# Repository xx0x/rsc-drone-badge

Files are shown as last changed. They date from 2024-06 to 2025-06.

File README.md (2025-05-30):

# RSC Drone Badge

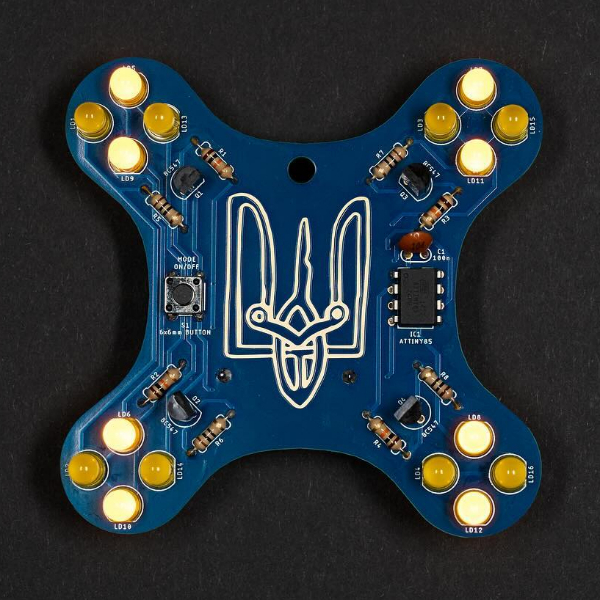
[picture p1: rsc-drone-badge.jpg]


A badge (pendant) in the shape of FPV drone which I designed for my friends at [Resistance Support Club](http://resistance.support). The collective organizes soldering workshops, the collected money goes to Ukrainian defenders.

## BOM (Bill of Material)
<table>
    <tr>
        <th>Part</th>
        <th>Value</th>
        <th>Package</th>
        <th>Part number</th>
        <th>Qty</th>
    </tr>
    <tr>
        <td>IC1</td>
        <td>ATTINY</td>
        <td>DIP8</td>
        <td>ATTINY25V-10PU</td>
        <td>1</td>
    </tr>
    <tr>
        <td>LD1, LD2, LD3, LD4,<br>LD5, LD6, LD7, LD8,<br>LD9, LD10, LD11, LD12,<br>LD13, LD14, LD15, LD16</td>
        <td>Yellow LED</td>
        <td>5mm THT</td>
        <td>N0Y64L35,<br>L-53SYD</td>
        <td>16</td>
    </tr>
    <tr>
        <td>Q1, Q2, Q3, Q4</td>
        <td>BC547</td>
        <td>TO92</td>
        <td>BC547A/B/C</td>
        <td>4</td>
    </tr>
    <tr>
        <td>R1, R2, R3, R4</td>
        <td>10K</td>
        <td>0207</td>
        <td>CF1/4W-10K</td>
        <td>4</td>
    </tr>
    <tr>
        <td>R5, R6, R7, R8</td>
        <td>10R</td>
        <td>0207</td>
        <td>CF1/4W-10R</td>
        <td>4</td>
    </tr>
    <tr>
        <td>C1</td>
        <td>100n</td>
        <td>2.54 ceramic</td>
        <td>CC-100N</td>
        <td>1</td>
    </tr>
    <tr>
        <td>S1</td>
        <td>Tactile button</td>
        <td>6x6mm</td>
        <td>TACT-64K-F,<br>B3F-1020</td>
        <td>1</td>
    </tr>
    <tr>
        <td>BAT</td>
        <td>Battery holder</td>
        <td>CR2032</td>
        <td>DS1092-04-B6P</td>
        <td>1</td>
    </tr>
</table>

Then you just need a regular CR2032 battery and a 2 mm polypropylen, nylon or other string from your local store.

## Description

Custom designed PCB in Eagle, you can find both design files and gerber archive in the `pcb` subfolder. You can easily download the ZIP file with gerber and order the PCBs at your favorite PCB manufacturer. Recommended options are: Blue soldermask, ENIG surface.

The board contains ATtiny 25 MCU, you can find a precompiled HEX and shell upload script in `build` folder. Or you can compile it by yourself, eg. to run on another MCU like ATtiny 85. The source files are in the `code` folder, you'll need Arduino IDE with ATTinyCore for compiling them.

In `drawing` subfolder you can find board drawings in Adobe Illustrator format and a PDF with BOM and build instructions.

Слава Україні! 🇺🇦

## Mini Variant

The directories also contain a simplified variant, smaller with 4 LEDs.

## License

MIT, feel free to share!

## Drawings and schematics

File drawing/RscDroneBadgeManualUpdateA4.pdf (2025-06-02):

# RSC Přívěsek RSC Přívěsek

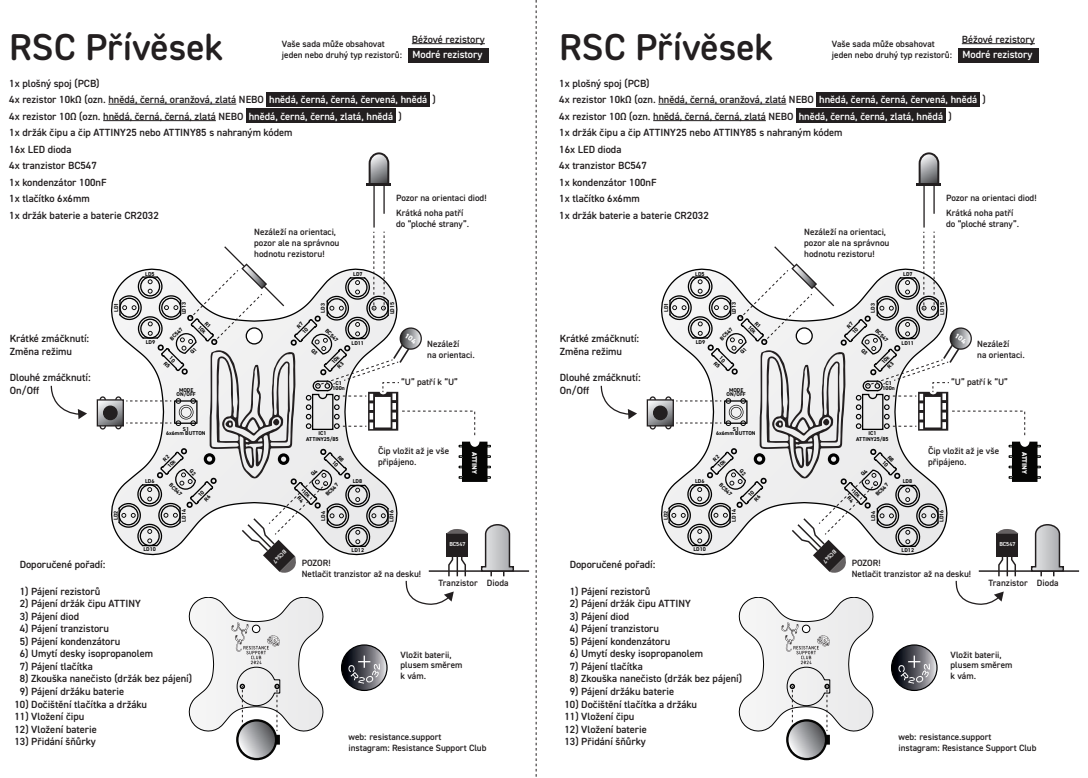
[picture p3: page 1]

Vaše sada může obsahovat
jeden nebo druhý typ rezistorů:

1x plošný spoj (PCB)
4x rezistor 10kΩ (ozn. hnědá, černá, oranžová, zlatá NEBO hnědá, černá, černá, červená, hnědá )
4x rezistor 10Ω (ozn. hnědá, černá, černá, zlatá NEBO hnědá, černá, černá, zlatá, hnědá )
1x držák čipu a čip ATTINY25 nebo ATTINY85 s nahraným kódem
16x LED dioda
4x tranzistor BC547
1x kondenzátor 100nF
1x tlačítko 6x6mm
1x držák baterie a baterie CR2032

Pozor na orientaci diod!
Krátká noha patří
do “ploché strany”.

Nezáleží na orientaci,
pozor ale na správnou
hodnotu rezistoru!

Čip vložit až je vše
připájeno.

POZOR!
Netlačit tranzistor až na desku!

1) Pájení rezistorů
2) Pájení držák čipu ATTINY
3) Pájení diod
4) Pájení tranzistoru
5) Pájení kondenzátoru
6) Umytí desky isopropanolem
7) Pájení tlačítka
8) Zkouška nanečisto (držák bez pájení)
9) Pájení držáku baterie
10) Dočištění tlačítka a držáku
11) Vložení čipu
12) Vložení baterie
13) Přidání šňůrky

web: resistance.support
instagram: Resistance Support Club

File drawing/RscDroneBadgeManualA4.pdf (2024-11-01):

# RSC Přívěsek RSC Přívěsek

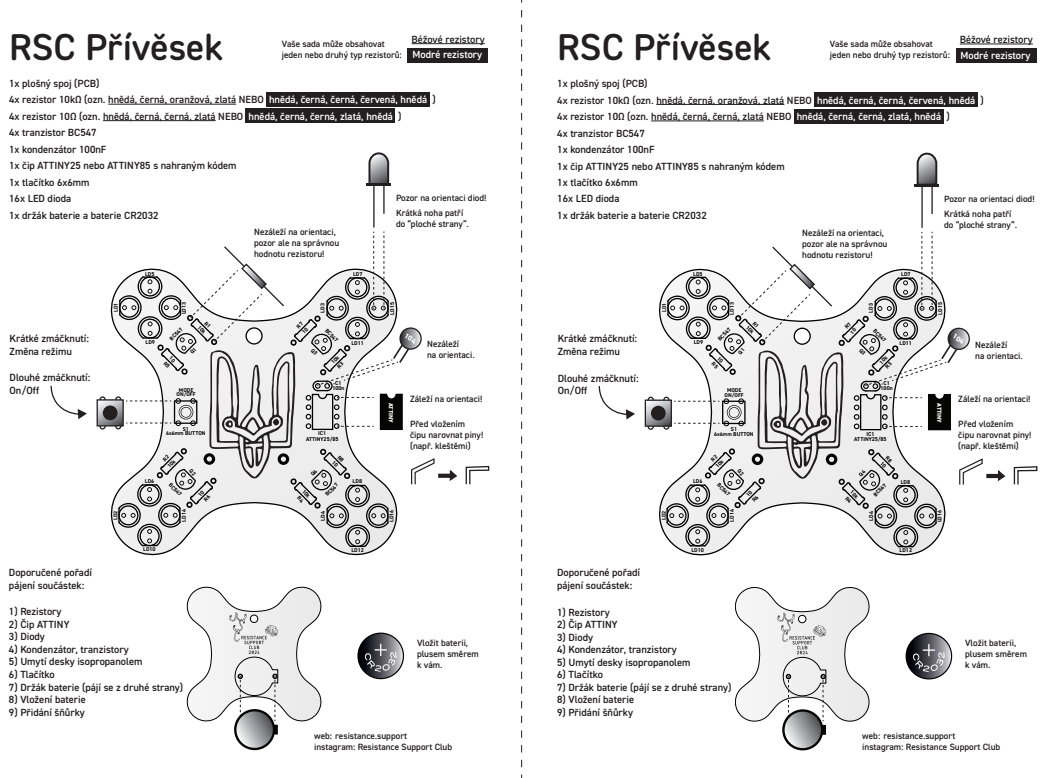
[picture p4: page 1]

Vaše sada může obsahovat
jeden nebo druhý typ rezistorů:

1x plošný spoj (PCB)
4x rezistor 10kΩ (ozn. hnědá, černá, oranžová, zlatá NEBO hnědá, černá, černá, červená, hnědá )
4x rezistor 10Ω (ozn. hnědá, černá, černá, zlatá NEBO hnědá, černá, černá, zlatá, hnědá )
4x tranzistor BC547
1x kondenzátor 100nF
1x čip ATTINY25 nebo ATTINY85 s nahraným kódem
1x tlačítko 6x6mm
16x LED dioda
1x držák baterie a baterie CR2032

Pozor na orientaci diod!
Krátká noha patří
do “ploché strany”.

Nezáleží na orientaci,
pozor ale na správnou
hodnotu rezistoru!

1) Rezistory
2) Čip ATTINY
3) Diody
4) Kondenzátor, tranzistory
5) Umytí desky isopropanolem
6) Tlačítko
7) Držák baterie (pájí se z druhé strany)
8) Vložení baterie
9) Přidání šňůrky

web: resistance.support
instagram: Resistance Support Club

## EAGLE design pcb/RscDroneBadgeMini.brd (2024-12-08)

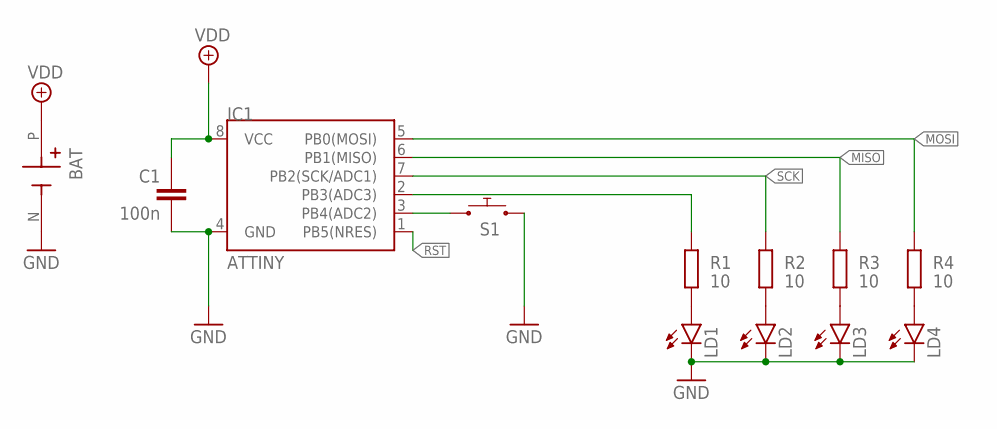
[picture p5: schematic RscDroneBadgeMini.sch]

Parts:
BAT: CR2032; CR2032_PLASTIC
C1: 100n; C_2.54
IC1: ATTINY; DIL08
LD1, LD2, LD3, LD4: LED_THT-5MM_NICE; LED_5MM_NICE
R1, R2, R3, R4: 10; RCL_0207
S1: 6x6mm BUTTON; TACTILE-PTH

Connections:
GND: BAT.N (NEG), C1.2, IC1.4 (GND), LD1.K (C), LD2.K (C), LD3.K (C), LD4.K (C), S1.3 (2), S1.4 (2)
MISO: IC1.6 (PB1(MISO)), R3.2
MOSI: IC1.5 (PB0(MOSI)), R4.2
unnamed: IC1.3 (PB4(ADC2)), S1.1, S1.2 (1)
unnamed: LD1.A, R1.1
unnamed: LD2.A, R2.1
unnamed: LD3.A, R3.1
unnamed: LD4.A, R4.1
unnamed: IC1.2 (PB3(ADC3)), R1.2
RST: IC1.1 (PB5(NRES))
SCK: IC1.7 (PB2(SCK/ADC1)), R2.2
VDD: BAT.P (POS), C1.1, IC1.8 (VCC)

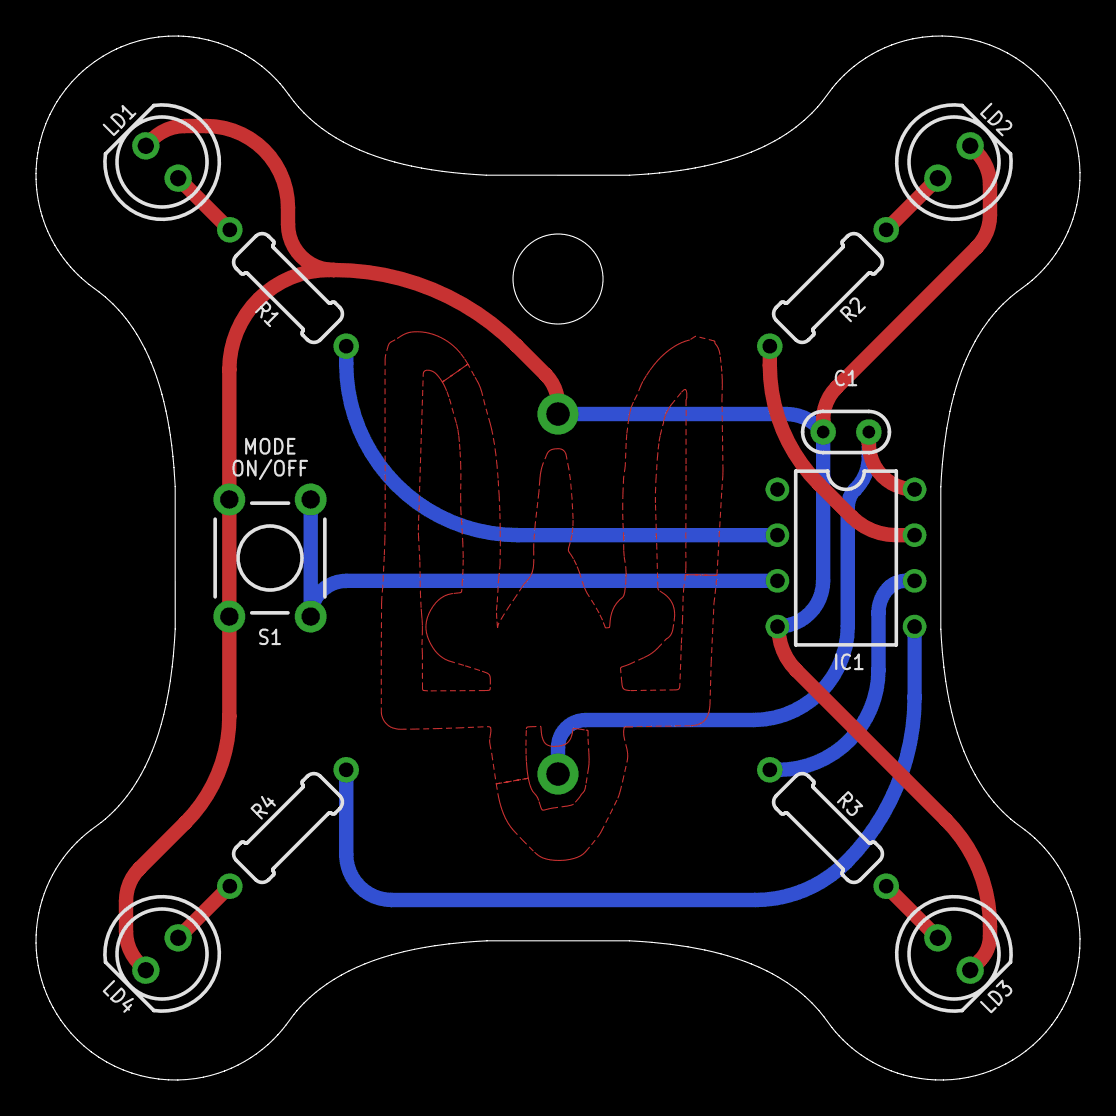
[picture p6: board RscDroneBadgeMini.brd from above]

Board: 2 copper layers, 58.0 x 58.0 mm, 12 parts (1 on the bottom side), 11 nets.

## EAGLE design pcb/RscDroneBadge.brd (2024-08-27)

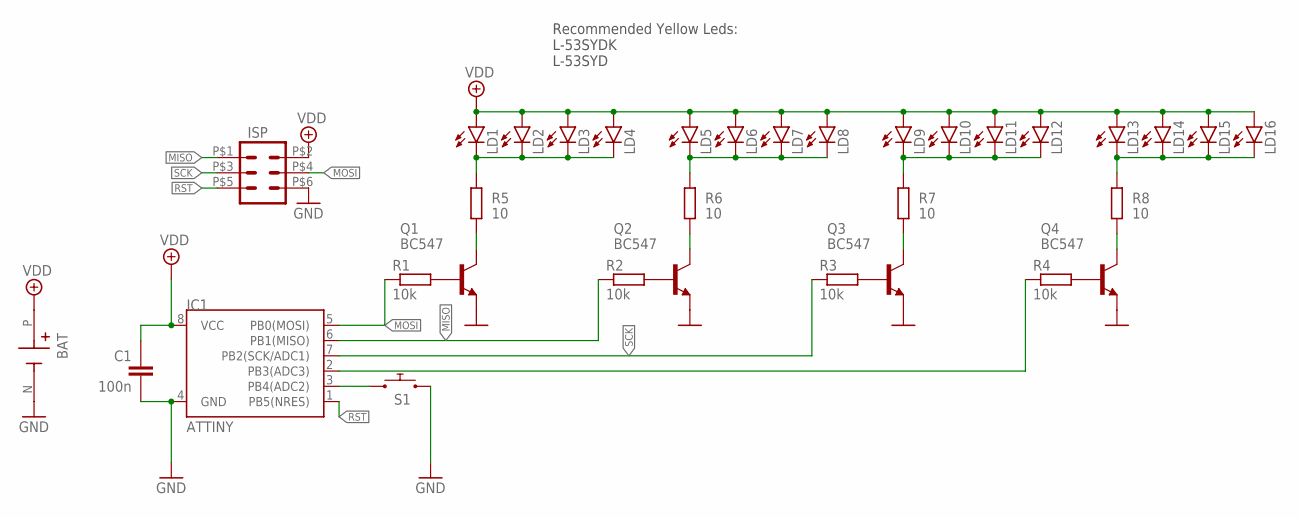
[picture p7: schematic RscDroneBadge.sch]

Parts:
BAT: CR2032 HOLDER; CR2032_PLASTIC
C1: 100n; C_2.54
IC1: ATTINY; DIL08
ISP: 2X3POGONO_VIA; 2X3_POGO_NO_VIA
LD1, LD2, LD3, LD4, LD5, LD6, LD7, LD8, LD9, LD10, LD11, LD12, LD13, LD14, LD15, LD16: LED_THT-5MM_NICE; LED_5MM_NICE
Q1, Q2, Q3, Q4: BC547; TO92_ROUND
R1, R2, R3, R4: 10k; RCL_0207
R5, R6, R7, R8: 10; RCL_0207
S1: 6x6mm BUTTON; TACTILE-PTH

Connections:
GND: BAT.N (NEG), C1.2, IC1.4 (GND), ISP.P$6 (6), Q1.1 (E), Q2.1 (E), Q3.1 (E), Q4.1 (E), S1.3 (2), S1.4 (2)
MISO: IC1.6 (PB1(MISO)), ISP.P$1 (1), R2.1
MOSI: IC1.5 (PB0(MOSI)), ISP.P$4 (4), R1.1
unnamed: IC1.3 (PB4(ADC2)), S1.1, S1.2 (1)
unnamed: Q1.2 (B), R1.2
unnamed: Q2.2 (B), R2.2
unnamed: Q3.2 (B), R3.2
unnamed: Q4.2 (B), R4.2
unnamed: IC1.2 (PB3(ADC3)), R4.1
unnamed: Q1.3 (C), R5.1
unnamed: Q2.3 (C), R6.1
unnamed: Q3.3 (C), R7.1
unnamed: Q4.3 (C), R8.1
unnamed: LD9.K (C), LD10.K (C), LD11.K (C), LD12.K (C), R7.2
unnamed: LD13.K (C), LD14.K (C), LD15.K (C), LD16.K (C), R8.2
unnamed: LD5.K (C), LD6.K (C), LD7.K (C), LD8.K (C), R6.2
unnamed: LD1.K (C), LD2.K (C), LD3.K (C), LD4.K (C), R5.2
RST: IC1.1 (PB5(NRES)), ISP.P$5 (5)
SCK: IC1.7 (PB2(SCK/ADC1)), ISP.P$3 (3), R3.1
VDD: BAT.P (POS), C1.1, IC1.8 (VCC), ISP.P$2 (2), LD1.A, LD2.A, LD3.A, LD4.A, LD5.A, LD6.A, LD7.A, LD8.A, LD9.A, LD10.A, LD11.A, LD12.A, LD13.A, LD14.A, LD15.A, LD16.A

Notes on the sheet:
Recommended Yellow Leds: L-53SYDK L-53SYD

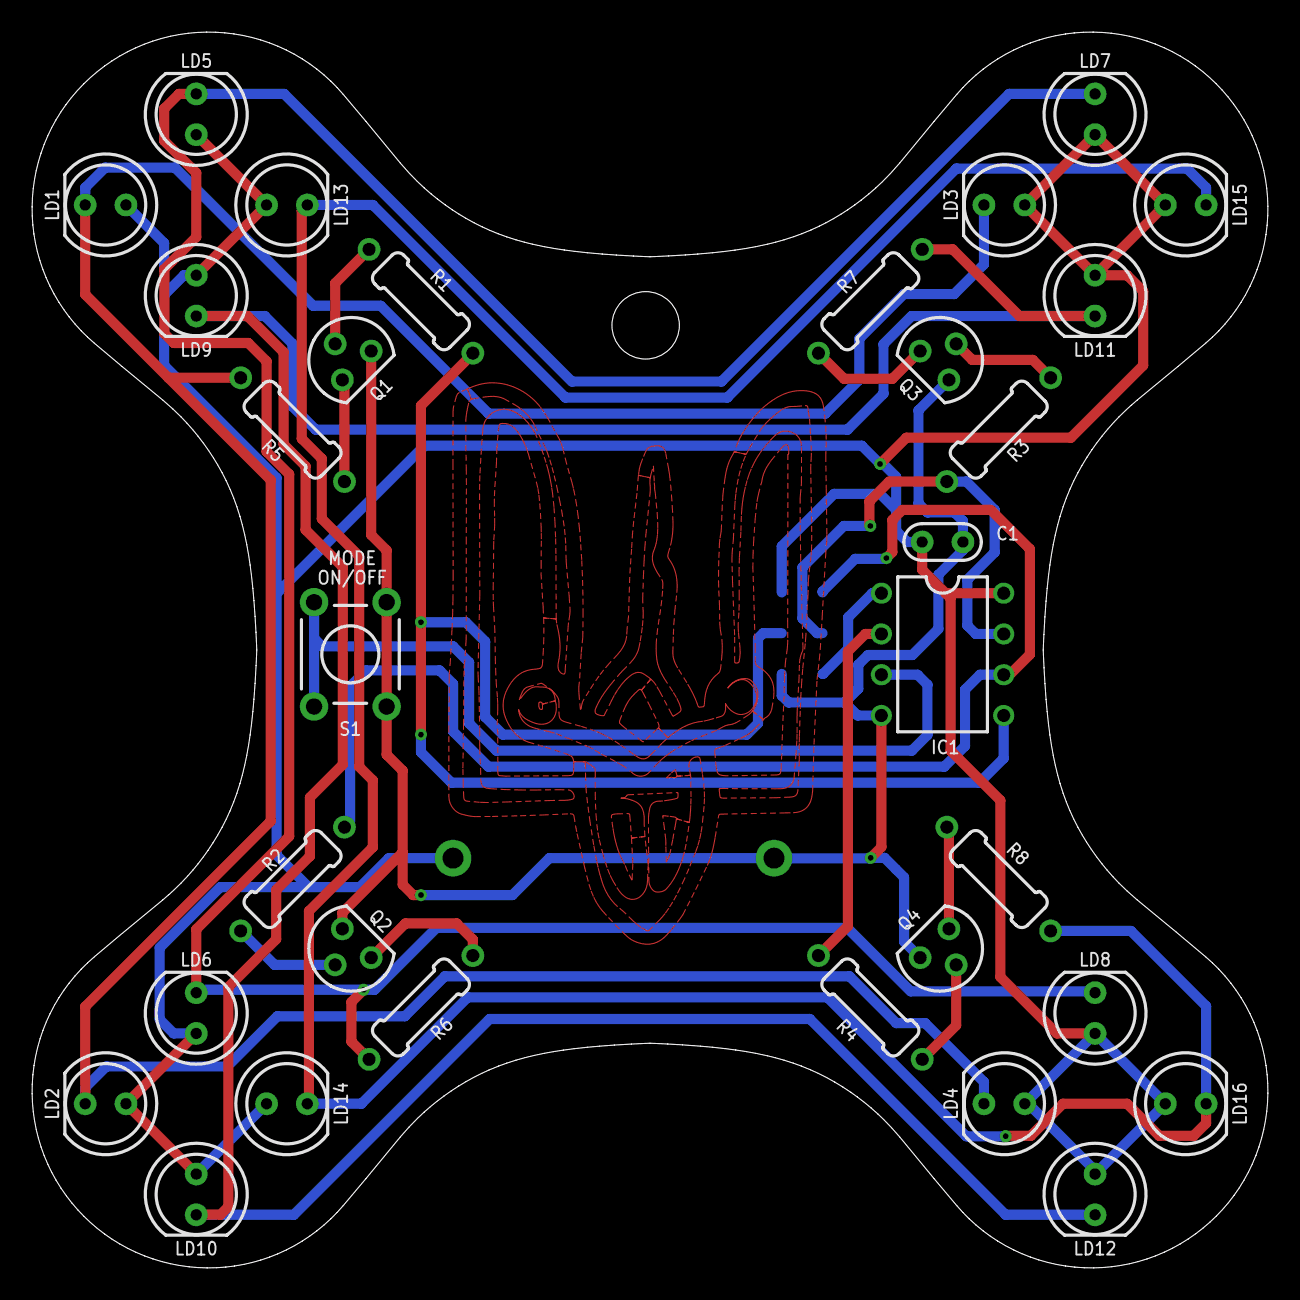
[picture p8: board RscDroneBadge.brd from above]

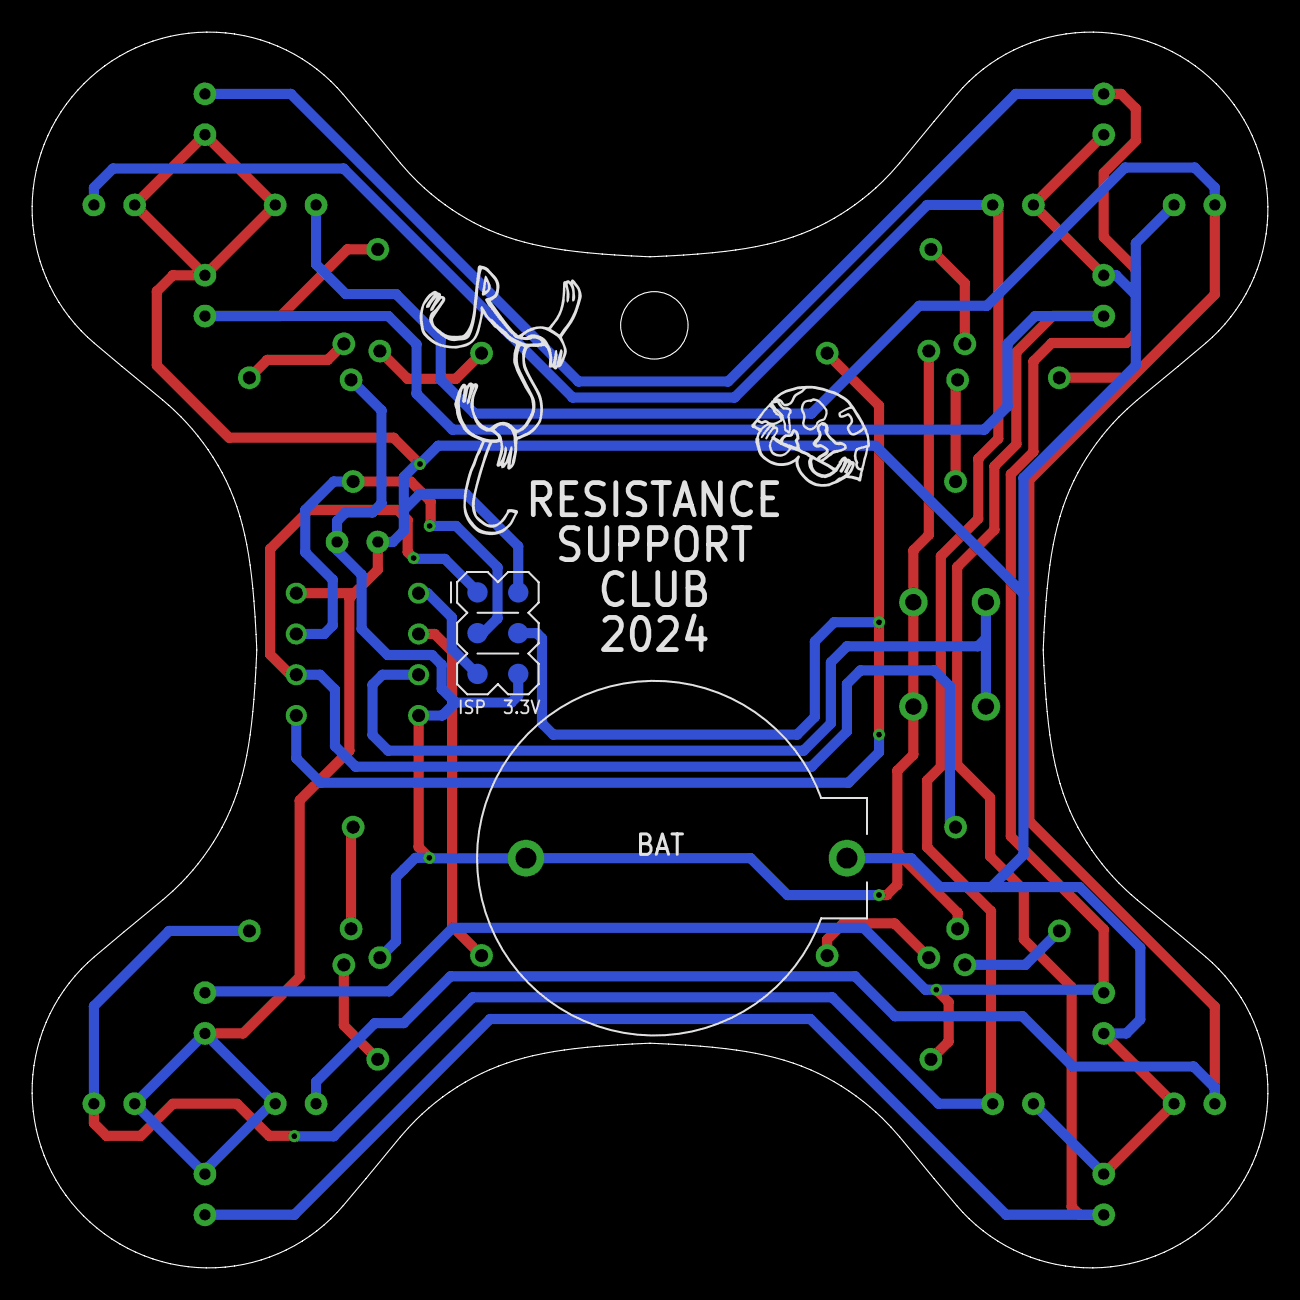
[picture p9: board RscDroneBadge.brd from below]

Board: 2 copper layers, 77.0 x 77.0 mm, 33 parts (2 on the bottom side), 20 nets.

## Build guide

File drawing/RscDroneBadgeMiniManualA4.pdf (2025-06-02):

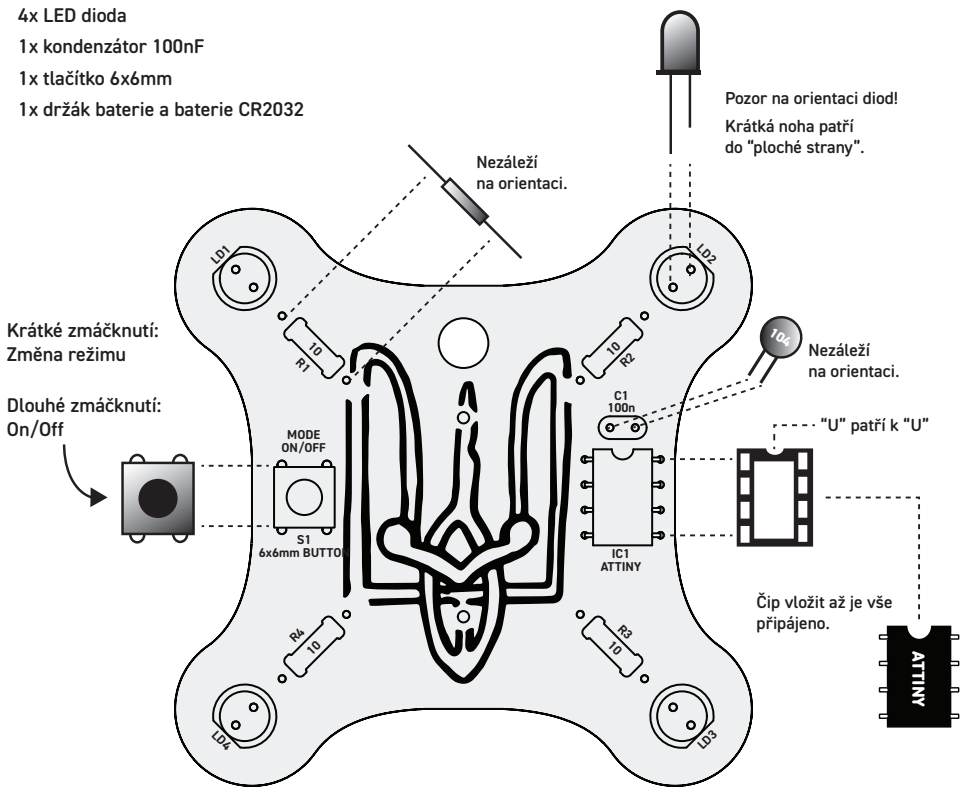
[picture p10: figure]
S1 6x6mm BUTTON; MODE ON/OFF; IC1 ATTINY; 4x LED dioda 1x kondenzátor 100nF 1x tlačítko 6x6mm; Krátká noha patří do “ploché strany”.; Nezáleží na orientaci.; “U” patří k “U”; ATTINY; Krátké zmáčknutí: Změna režimu; Dlouhé zmáčknutí: On/Off; Čip vložit až je vše připájeno.

RESISTANCE SUPPORT
CLUB 2024

# RSC Přívěsek

1x plošný spoj (PCB)
4x rezistor 10Ω (ozn. hnědá, černá, černá, zlatá NEBO hnědá, černá, černá, zlatá, hnědá ) 1x držák čipu a samotný čip ATTINY25 nebo ATTINY85 s nahraným kódem

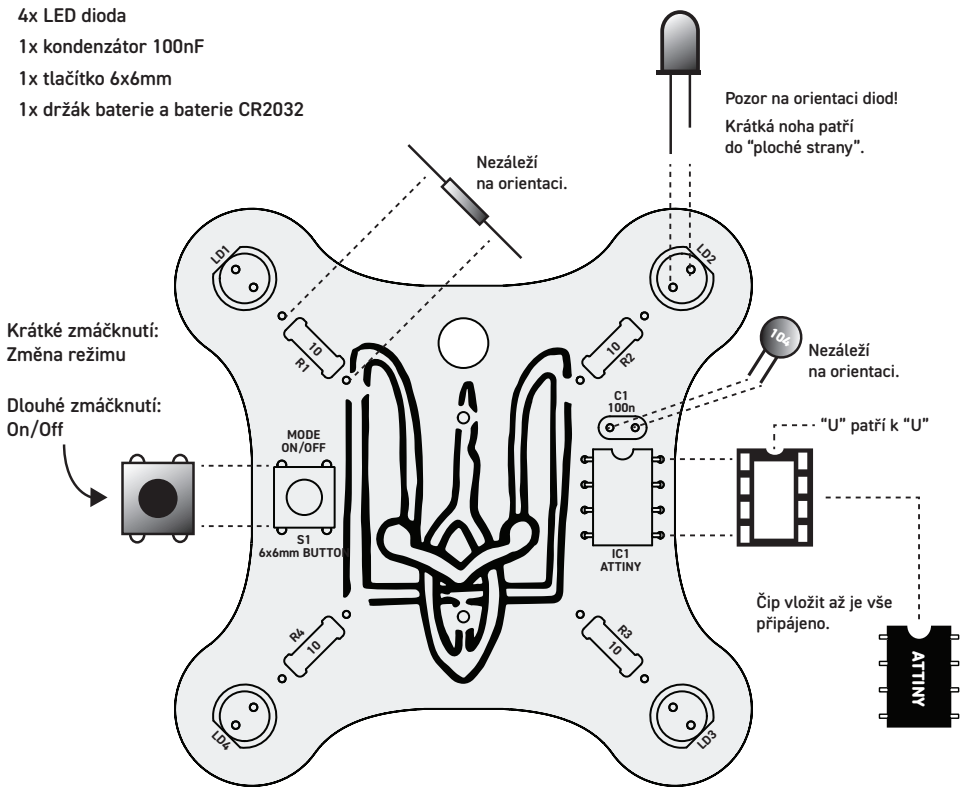
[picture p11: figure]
S1 6x6mm BUTTON; MODE ON/OFF; IC1 ATTINY; 4x LED dioda 1x kondenzátor 100nF 1x tlačítko 6x6mm; Krátká noha patří do “ploché strany”.; Nezáleží na orientaci.; “U” patří k “U”; ATTINY; Krátké zmáčknutí: Změna režimu; Dlouhé zmáčknutí: On/Off; Čip vložit až je vše připájeno.

1x držák baterie a baterie CR2032 | Pozor na orientaci diod!

Vložit baterii,
plusem směrem
k vám.

Béžové rezistory
Modré rezistory

Vaše sada může obsahovat
jeden nebo druhý typ rezistorů:

Doporučené pořadí:

1) Pájení rezistorů
2) Pájení držák čipu ATTINY
3) Pájení diod
4) Pájení kondenzátoru
5) Umytí desky isopropanolem
6) Pájení tlačítka
7) Zkouška nanečisto (držák bez pájení)
8) Pájení držáku baterie
9) Dočištění tlačítka a držáku
10) Vložení čipu
11) Vložení baterie
12) Přidání šňůrky
web: resistance.support
instagram: Resistance Support Club

## MINI

RESISTANCE SUPPORT
CLUB 2024

# RSC Přívěsek

1x plošný spoj (PCB)
4x rezistor 10Ω (ozn. hnědá, černá, černá, zlatá NEBO hnědá, černá, černá, zlatá, hnědá ) 1x držák čipu a samotný čip ATTINY25 nebo ATTINY85 s nahraným kódem
1x držák baterie a baterie CR2032 | Pozor na orientaci diod!

Vložit baterii,
plusem směrem
k vám.

Béžové rezistory
Modré rezistory

Vaše sada může obsahovat
jeden nebo druhý typ rezistorů:

Doporučené pořadí:

1) Pájení rezistorů
2) Pájení držák čipu ATTINY
3) Pájení diod
4) Pájení kondenzátoru
5) Umytí desky isopropanolem
6) Pájení tlačítka
7) Zkouška nanečisto (držák bez pájení)
8) Pájení držáku baterie
9) Dočištění tlačítka a držáku
10) Vložení čipu
11) Vložení baterie
12) Přidání šňůrky
web: resistance.support
instagram: Resistance Support Club

## MINI

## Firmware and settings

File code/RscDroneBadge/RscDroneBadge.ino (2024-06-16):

/**
 * Code for RSC DRONE BADGE
 * MCU: ATTINY25 @ 8 MHz
 * Using: Arduino + ATTinyCore
 * Author: Vaclav M (github.com/xx0x)
 * Licence: MIT
 *
 * Ugly code, sorry, I wrote in a hurry and didn't have time to clean it :(
 * But it works :)
 */

#include <avr/interrupt.h>
#include <avr/sleep.h>


#define LEDS 4
uint8_t ledPins[LEDS] = { 0, 1, 3, 2 };
uint8_t ledPinsFast[LEDS] = { PB0, PB1, PB3, PB2 };

#define SET_STATE_HIGH(pin_name) (PORTB |= (1 << pin_name))
#define SET_STATE_LOW(pin_name) (PORTB &= ~(1 << pin_name))
#define SET_STATE(pin_name, state) ((state) ? SET_STATE_HIGH(pin_name) : SET_STATE_LOW(pin_name))

#define ON HIGH
#define OFF LOW

#define PIN_BUTTON 4
#define BUTTON_PRESSED LOW

#define INTERVAL_NORMAL 250
#define INTERVAL_FAST 100

/*
 * Animations
 */
byte animationType = 0;                // current animation
unsigned int animationInterval = 250;  // interval between animation frames
byte animationFrame = 0;               // current animation frame
unsigned long lastTime = 0;            // last time in milliseconds the frame changed
byte animationEnabled = true;          // whether animations enabled

/*
 * PWM - brightness settings
 */
#define PWM_MODES 4
byte currentPwmMode = 0;
byte pwmModes[PWM_MODES] = { 0, 10, 50, 250 };
byte pwmIndex = 0;


/*
 * Buttons
 */
bool buttonPressed = false;        // whether mode button pressed last time
unsigned long lastTimeButton = 0;  // last time - used for turning off
bool modeChangeDisabled = false;   // if changing pwm or turning on, mode change disabled when button released

/*
 * Turn off interval
 */
#define TURN_OFF_INTERVAL 1000


bool leds[LEDS] = { 0, 0, 0, 0 };

#define ANIMATIONS 9  // animations count
#define ANIMATION_RANDOM 8
uint8_t randomAnimation = 1;
uint16_t randomFramesCounter = 0;

void animate() {

  animationInterval = INTERVAL_NORMAL;
  uint8_t animationTypeNow = animationType;
  if(animationTypeNow == ANIMATION_RANDOM){
    randomFramesCounter++;
    if(randomFramesCounter > 8){
        byte x = 0;
        do {
            x = (rand() % 7) + 1;
        } while(x == randomAnimation);
        randomAnimation = x;
        randomFramesCounter = 0;
        animationFrame = 0;
    }
    animationTypeNow = randomAnimation;
  }

  switch (animationTypeNow) {
    case 0:
      animationOn();
      break;
    case 1:
      animationAllBlink();
      break;
    case 2:
      animationRotateProper();
      break;
    case 3:
      animationInterval = INTERVAL_FAST;
      animationRotateProper();
      break;
    case 4:
      animationRotate();
      break;
    case 5:
      animationInterval = INTERVAL_FAST;
      animationRotate();
      break;
    case 6:
      animationRotateBackwards();
      break;
    case 7:
      animationInterval = INTERVAL_FAST;
      animationRotateBackwards();
      break;
  }
}

void animationOff() {
  for (uint8_t i = 0; i < LEDS; i++) {
    leds[i] = 0;
  }
}

void animationOn() {
  for (uint8_t i = 0; i < LEDS; i++) {
    leds[i] = 1;
  }
}

void animationAllBlink() {
  switch (animationFrame) {
    case 0:
      animationOn();
      animationFrame++;
      break;
    case 1:
      animationOff();
      animationFrame = 0;
      break;
  }
}

void animationRotate() {
  animationFrame = (animationFrame + 1) % LEDS;
  animationOff();
  leds[animationFrame] = 1;
}

void animationRotateBackwards() {
  animationFrame = (animationFrame + 1) % LEDS;
  animationOff();
  leds[LEDS - animationFrame - 1] = 1;
}

void animationRotateProper() {
  animationFrame = (animationFrame + 1) % 2;
  animationOff();
  leds[animationFrame] = 1;
  leds[animationFrame + 2] = 1;
}

void animationRandom() {
  for (uint8_t i = 0; i < LEDS; i++) {
    leds[i] = (random(10) > 7);
  }
}


/* 
 *  The setup function runs once when the battery is inserted (not when "turned off" via button)
 */
void setup() {
  for (uint8_t i = 0; i < LEDS; i++) {
    pinMode(ledPins[i], OUTPUT);
  }
  pinMode(PIN_BUTTON, INPUT_PULLUP);
}


/* 
 * The loop function runs over and over again forever
 */
void loop() {

  // debounce to prevent double taps
  if (millis() - lastTimeButton > 200) {
    /*
     * BUTTON MODE switches animations, but after is released (because of PWM and turning off)
     */
    if (digitalRead(PIN_BUTTON) == BUTTON_PRESSED) {
      if (!buttonPressed) {
        buttonPressed = true;
        lastTimeButton = millis();
      }
      checkWhetherToSleep();  // checking whether to sleep
    } else {

      lastTimeButton = 0;

      // if mode released, change mode
      if (buttonPressed) {
        if (!modeChangeDisabled) {  // changing modes is disabled after waking up
          lastTime = 0;
          animationType = (animationType + 1) % ANIMATIONS;
          if (animationType == 0) {
            currentPwmMode = (currentPwmMode + 1) % PWM_MODES;
          }
          animationFrame = 0;
        }
        modeChangeDisabled = false;
        lastTimeButton = millis();
      }
      buttonPressed = false;
    }
  }

  /*
     * Doing animation and PWM!
     */
  if (animationEnabled) {
    doAnimation();
    updateLeds();
  }
}

/*
 * Whether is time to do animation
 */
void doAnimation() {
  if (millis() - lastTime < animationInterval) {  // check whether is the time to do it
    return;
  }

  lastTime = millis();
  animate();
}

/*
 * Checks whether MODE has been pressed for too long, if so, go to sleep - then wake up
 */
void checkWhetherToSleep() {
  if (lastTimeButton == 0) return;

  if (millis() - lastTimeButton > TURN_OFF_INTERVAL) {
    animationOff();
    animationEnabled = false;
    updateLeds();
    delay(200);  // for person to have a little time to put their finger off

    // NOW GOING TO SLEEP
    sleep();
    // NOW WAKING UP

    lastTimeButton = 0;
    animationEnabled = true;
    modeChangeDisabled = true;
  }
}


/*
 * This is called when the interrupt occurs - button pressed, but we don't need to do anything in it
 */

ISR(PCINT0_vect) {
}


/* 
 *  Doing sleep
 *  
 *  The sleep is interrupted by even shortest pressing MODE,
 *  but then there is a check, wheter the button is pressed for longer time to prevent unwanted waking-ups
 *  
 */
void sleep() {
  GIMSK |= _BV(PCIE);                   // Enable Pin Change Interrupts
  PCMSK |= _BV(PCINT4);                 // Use PB4 as interrupt pin
  ADCSRA &= ~_BV(ADEN);                 // ADC off
  set_sleep_mode(SLEEP_MODE_PWR_DOWN);  // replaces above statement
  sleep_enable();                       // Sets the Sleep Enable bit in the MCUCR Register (SE BIT)
  sei();                                // Enable interrupts
  sleep_cpu();                          // sleep

  // NOW WAKING UP
  cli();                  // Disable interrupts
  PCMSK &= ~_BV(PCINT4);  // Turn off PB4 as interrupt pin
  sleep_disable();        // Clear SE bit
  ADCSRA |= _BV(ADEN);    // ADC on
  sei();                  // Enable interrupts

  // CHECK WHETHER THE BUTTON IS PRESSED FOR 1s, if not, sleep again
  bool slp = false;
  for (byte i = 0; i < 4; i++) {
    delay(250);
    if (digitalRead(PIN_BUTTON) != BUTTON_PRESSED) {
      slp = true;
      break;
    }
  }
  if (slp) {
    sleep();
  }
}


void updateLeds() {
  if (pwmIndex > pwmModes[currentPwmMode]) {
    pwmIndex = 0;
  } else {
    pwmIndex++;
  }
  if (pwmIndex == 0) {
    for (uint8_t i = 0; i < LEDS; i++) {
      SET_STATE(ledPinsFast[i], leds[i]);
      //digitalWrite(ledPins[i], leds[i]);
    }

  } else {
    for (uint8_t i = 0; i < LEDS; i++) {
      SET_STATE_LOW(ledPinsFast[i]);
      //digitalWrite(ledPins[i], false);
    }
  }
}

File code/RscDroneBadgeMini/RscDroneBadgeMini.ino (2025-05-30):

/**
 * Code for RSC DRONE BADGE (Mini Variant with 4 LEDs)
 * MCU: ATTINY25 @ 8 MHz
 * Using: Arduino + ATTinyCore
 * Author: Vaclav M (github.com/xx0x)
 * Licence: MIT
 */

#include <avr/interrupt.h>
#include <avr/sleep.h>

// LED configuration
#define LEDS 4
const uint8_t ledPinsFast[LEDS] = {PB0, PB1, PB3, PB2};

#define SET_STATE_HIGH(pin_name) (PORTB |= (1 << pin_name))
#define SET_STATE_LOW(pin_name) (PORTB &= ~(1 << pin_name))
#define SET_STATE(pin_name, state) ((state) ? SET_STATE_HIGH(pin_name) : SET_STATE_LOW(pin_name))

#define PIN_BUTTON 4
#define BUTTON_PRESSED LOW

#define INTERVAL_NORMAL 250
#define INTERVAL_FAST 100
#define TURN_OFF_INTERVAL 1000

// Animations
uint8_t animationType = 0;          // current animation
uint8_t animationFrame = 0;         // current animation frame
uint8_t animationEnabled = 1;       // whether animations enabled
uint8_t animationInterval = INTERVAL_NORMAL; // interval between animation frames

// Button state tracking
uint8_t buttonPressed = 0;       
uint8_t modeChangeDisabled = 0;

// Timing variables
unsigned long lastTime = 0;
unsigned long lastTimeButton = 0;

// LED states
uint8_t leds[LEDS];

// Animation defines
#define ANIMATIONS 11
#define ANIMATION_RANDOM 10
uint8_t randomAnimation = 1;
uint8_t randomFramesCounter = 0;

// Forward declarations
void animate(void);
void updateLeds(void);
void sleep(void);
void animationOff(void);

void setup() {
  // Set LED pins as outputs
  DDRB |= ((1 << PB0) | (1 << PB1) | (1 << PB2) | (1 << PB3));
  
  // Set button pin as input with pullup
  pinMode(PIN_BUTTON, INPUT_PULLUP);
}

void loop() {
  // Debounce to prevent double taps
  if (millis() - lastTimeButton > 200) {
    if (digitalRead(PIN_BUTTON) == BUTTON_PRESSED) {
      if (!buttonPressed) {
        buttonPressed = 1;
        lastTimeButton = millis();
      }
      // Check whether to sleep
      if (lastTimeButton && (millis() - lastTimeButton > TURN_OFF_INTERVAL)) {
        animationOff();
        animationEnabled = 0;
        updateLeds();
        delay(200);
        sleep();
        lastTimeButton = 0;
        animationEnabled = 1;
        modeChangeDisabled = 1;
      }
    } else {
      lastTimeButton = 0;
      
      // If mode released, change mode
      if (buttonPressed) {
        if (!modeChangeDisabled) {
          lastTime = 0;
          animationType = (animationType + 1) % ANIMATIONS;
          animationFrame = 0;
        }
        modeChangeDisabled = 0;
        lastTimeButton = millis();
      }
      buttonPressed = 0;
    }
  }

  // Handle animation and update LEDs
  if (animationEnabled) {
    // Check if it's time for a new animation frame
    if (millis() - lastTime >= animationInterval) {
      lastTime = millis();
      animate();
    }
    updateLeds();
  }
}

// Empty interrupt handler
ISR(PCINT0_vect) {}

void sleep() {
  GIMSK |= _BV(PCIE);                  // Enable Pin Change Interrupts
  PCMSK |= _BV(PCINT4);                // Use PB4 as interrupt pin
  ADCSRA &= ~_BV(ADEN);                // ADC off
  set_sleep_mode(SLEEP_MODE_PWR_DOWN);
  sleep_enable();
  sei();
  sleep_cpu();

  // Wake up
  cli();
  PCMSK &= ~_BV(PCINT4);
  sleep_disable();
  ADCSRA |= _BV(ADEN);
  sei();

  // Check if button is still pressed for 1s
  for (uint8_t i = 0; i < 4; i++) {
    delay(250);
    if (digitalRead(PIN_BUTTON) != BUTTON_PRESSED) {
      sleep();
      break;
    }
  }
}

void animate() {
  animationInterval = INTERVAL_NORMAL;
  uint8_t animationTypeNow = animationType;
  
  // Handle random animation selection
  if (animationTypeNow == ANIMATION_RANDOM) {
    if (++randomFramesCounter > 8) {
      uint8_t x;
      do {
        x = (rand() % 7) + 1;
      } while (x == randomAnimation);
      randomAnimation = x;
      randomFramesCounter = 0;
      animationFrame = 0;
    }
    animationTypeNow = randomAnimation;
  }

  // Reset all LEDs first
  animationOff();

  // Set animation speed
  if (animationTypeNow == 3 || animationTypeNow == 5 || 
      animationTypeNow == 7 || animationTypeNow == 9) {
    animationInterval = INTERVAL_FAST;
    animationTypeNow--; // Use the same pattern as the slower version
  }

  // Handle different animation patterns
  switch (animationTypeNow) {
    case 0: // All on
      for (uint8_t i = 0; i < LEDS; i++) leds[i] = 1;
      break;
      
    case 1: // All blink
      animationFrame ^= 1; // Toggle between 0 and 1
      if (animationFrame) {
        for (uint8_t i = 0; i < LEDS; i++) leds[i] = 1;
      }
      break;
      
    case 2: // Left-right
      animationFrame = (animationFrame + 1) % 2;
      leds[animationFrame] = 1;
      leds[animationFrame + 2] = 1;
      break;
      
    case 4: // Up-down
      animationFrame = (animationFrame + 1) % 2;
      if (animationFrame == 0) {
        leds[0] = leds[3] = 1;
      } else {
        leds[1] = leds[2] = 1;
      }
      break;
      
    case 6: // Rotate
      animationFrame = (animationFrame + 1) % LEDS;
      leds[(animationFrame == 0) ? 0 : (animationFrame == 1) ? 2 : (animationFrame == 2) ? 3 : 1] = 1;
      break;
      
    case 8: // Rotate backwards
      animationFrame = (animationFrame + 1) % LEDS;
      leds[(animationFrame == 0) ? 1 : (animationFrame == 1) ? 3 : (animationFrame == 2) ? 2 : 0] = 1;
      break;
  }
}

void animationOff() {
  for (uint8_t i = 0; i < LEDS; i++) {
    leds[i] = 0;
  }
}

void updateLeds() {
  for (uint8_t i = 0; i < LEDS; i++) {
    SET_STATE(ledPinsFast[i], leds[i]);
  }
}

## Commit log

2024-03-29 work in progress
    [RscDroneBadge.brd, RscDroneBadge.sch]
2024-03-29 update schematic and board, add drawing
    [RscDroneBadge.brd, RscDroneBadge.sch]
2024-03-29 alignment fix
    [RscDroneBadge.brd]
2024-05-08 add manual print file
2024-05-08 basic PWM working
2024-05-08 update manual print
2024-05-08 fix debounce, add upload script
    [RscDroneBadge.ino]
2024-08-27 remove "85" from ATTINY label on the board
    [RscDroneBadge.brd, RscDroneBadge.sch]
2024-08-27 remove old gerber
2024-08-27 add BOM to readme
2024-12-08 add "mini" variant of the badge
    [RscDroneBadgeMini.brd, RscDroneBadgeMini.sch]
2024-12-08 silkscreen fixes
    [RscDroneBadgeMini.brd]
